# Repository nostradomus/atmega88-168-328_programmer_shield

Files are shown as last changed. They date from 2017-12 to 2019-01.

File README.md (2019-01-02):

# Atmega88/168/328 ISP programmer shield for Arduino UNO boards
  and    (minimal)

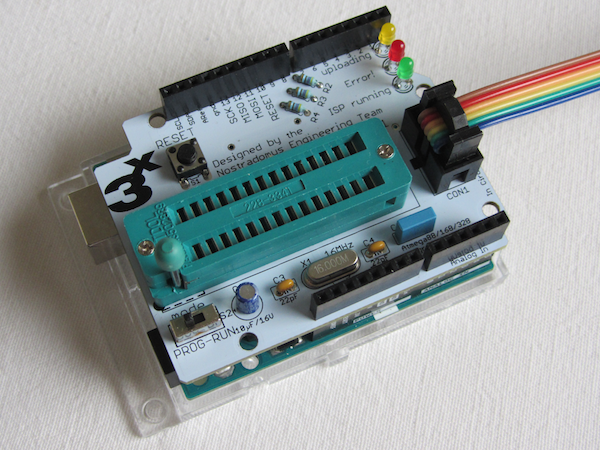
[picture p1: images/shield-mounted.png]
Shield on top of the Arduino board


## What

This repo provides you with all necessary info (and files) to build an Arduino shield to program [Atmel](http://www.atmel.com)'s **[atmega88/168/328](http://www.microchip.com/design-centers/8-bit/microchip-avr-mcus)** 𝜇-controllers. For that matter, the underlying Arduino board should be loaded with the [ISP-programmer sketch](source/ArduinoISP.ino) (built-in example). Two versions have been included. All images in the description below, refer to the 16MHz version with an external crystal oscillator. An alternative (minimalistic) version is also available in all respective sub-folders (marked as 'minimal'). It concerns a shield to program the same µ-controllers using their 8MHz internal clock.

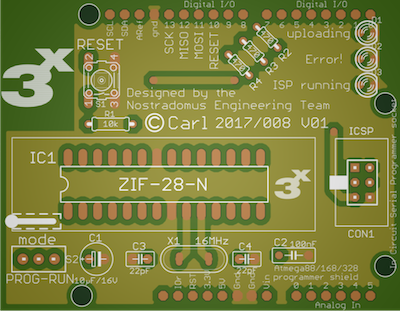
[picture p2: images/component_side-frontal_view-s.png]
PCB - component side
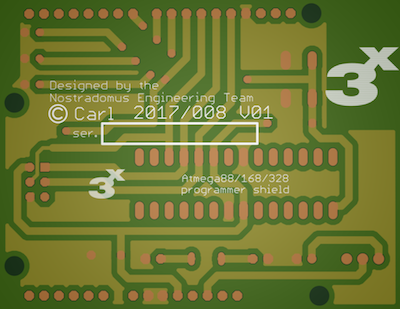
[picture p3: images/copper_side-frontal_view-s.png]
PCB - copper side
 

## Why

After having tested one of your new marvelous ideas with an existing eco-system, a lot of airwires and a piece of breadboard, you will probably start designing a state-of-the-art custom pcb to finalize the building of your project. During such a design phase, I however got tired of wiring up the ISPC connector over-and-over-again. As (like many people) I was having a spare UNO, which could serve as an [in-circuit serial programmer](https://en.wikipedia.org/wiki/In-system_programming), I decided to design a minimalistic shield to fit on top of it.  

## How

The shield has been designed with EAGLE from AutoDesk/CadSoft. This shield [project](eagle-files/) can be opened with the free version [(download here)](http://www.autodesk.com/products/eagle/free-download). Only [through-hole components](BOM.md) have been used in order to make the build also feasible for any junior electronics enthusiast. In the [pdf-folder](pdf-files/) of this repo pdf versions of all important EAGLE views are available, for those not wanting to install EAGLE. Pay attention to print the bottom and top-layer layouts **without re-sizing** (1:1). To have the printed circuit board built by a commercial PCB-shop, the full  [gerber-files](gerber-files/) are also available. When etching the board at home, don't forget to add the vias, or solder pieces of wire from solder to component side.

Currently, unpopulated boards for both the full and minimalistic version are still available from our workshop. If interested, [contact us via   :email:](http://nostradomus.ddns.net/contactform.html).

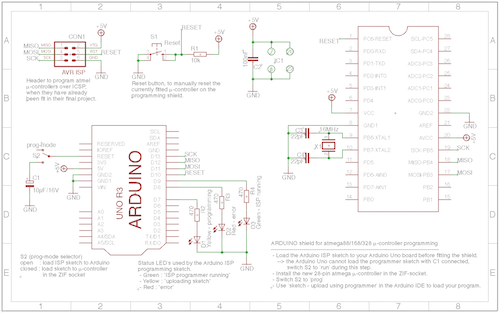
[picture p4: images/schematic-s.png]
Schematic
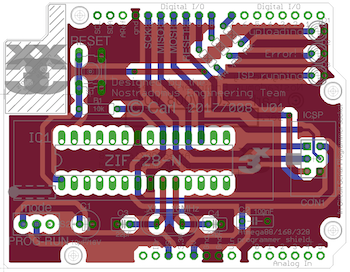
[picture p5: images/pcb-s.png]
PCB
 

## Technical details

### What’s on the board

The board has been fit with a narrow 28-pin [ZIF](https://en.wikipedia.org/wiki/Zero_insertion_force) socket, which is wired up to be universal for several types of AVR's. On the boarder of the PCB, pin headers with double functionality have been mounted. Pins on the bottom-side to fit on the Arduino board, and feed-through female headers on the top for easy access of all Arduino connections.
The push button, is connected to the reset lines of the [AVR](https://en.wikipedia.org/wiki/Atmel_AVR) in the ZIF socket (and the ICSP on the shield) with a 10kΩ pull-up resistor. When the shield is cut correctly, the reset button for the underlying Arduino UNO should still be accessible. In order to make the Arduino Uno work as an ISP programmer a 10µF capacitor needs to be connected on its reset-line.
Three LED’s are available to visualize the correct functionality of the programming procedure.
An optional AVR ISP connector has been foreseen in order to use the shield as stand-alone with a commercial programmer.

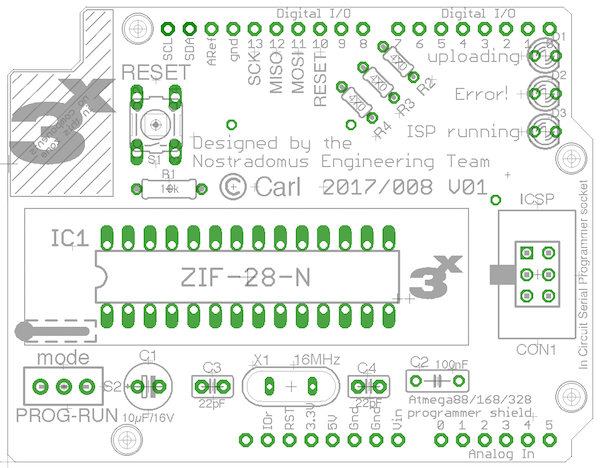
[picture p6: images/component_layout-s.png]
Component layout


#### BOM - bill of materials

Part   | Value          | Package      | Description  
------ | -------------- | ------------ | -----------                            
R1     | 10kΩ           | 0207/7       | resistor                                            
R2,3,4 | 470Ω           | 0204/5       | resistor                                            
C1     | 10µF/16V       | E2,5-6E      | polarized capacitor                                 
C2     | 100nF          | C050-025X075 | capacitor                                           
C3,4   | 22pF           | C2.5-2       | capacitor (version with xtal-oscillator)                                          
X1     | 16MHz          | QS           | oscillator crystal (version with xtal-oscillator)
LED1   | 3mm yellow     | 3mm          | LED                              
LED2   | 3mm red        | 3mm          | LED                              
LED3   | 3mm green      | 3mm          | LED
IC1    | 28-pin         | ZIF28-N      | 28-pin narrow ZIF-socket
ICSP1  | 2x3 pin-header | 2x3          | AVR ISP-6 Serial Programming Header (optional)
S1     | momentary      | 6x6x6mm      | momentary tact push button
S2     | toggle         | 9x4mm        | mini toggle switch
CON1   | 6-pin          | SIL06        | long needle female stackable pin header strip
CON2,3 | 8-pin          | SIL08        | long needle female stackable pin header strip
CON4   | 10-pin         | SIL10        | long needle female stackable pin header strip

### How things work

First the the [ISP-programmer sketch](sketches/ArduinoISP.ino) (built-in example) should be loaded to the Arduino UNO board. During that operation, switch S2 should be set to "RUN". Select “Arduino Uno” as target board in the tools-menu. Load the ISP-programmer sketch with the “UPLOAD” button. Once loaded, switch S2 can be set to "PROG" to send a sketch to the atmega 𝜇-controller in the ZIF socket.

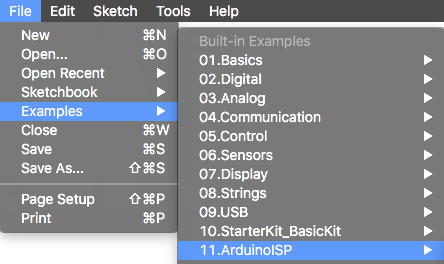
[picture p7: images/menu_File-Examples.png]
ISP example sketch
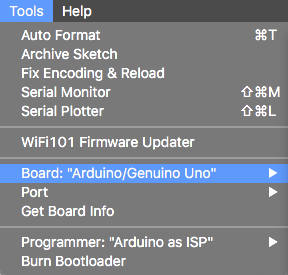
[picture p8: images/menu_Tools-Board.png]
Board selection
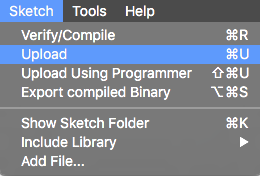
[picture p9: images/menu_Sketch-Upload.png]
Upload
  

To load a sketch to your atmega 𝜇-controller in the ZIF socket, make sure that the correct target board is selected in the tools-menu (you might need to download a specific library -> tools-menu, board manager). This time, use the “UPLOAD USING PROGRAMMER” option from the sketch-menu.

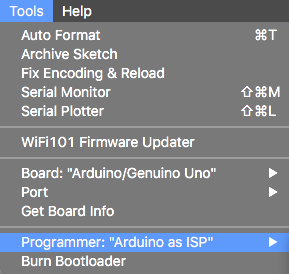
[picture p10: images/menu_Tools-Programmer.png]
Programmer selection
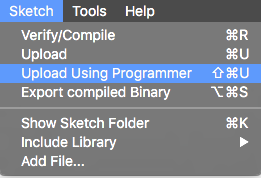
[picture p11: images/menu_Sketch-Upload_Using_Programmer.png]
Upload Using Programmer
 

When using the "8MHz internal clock" shield, an [adapted board configuration](source/minimal-boards.zip) should be used (read "fuse-settings"), which can be found in the [source-folder](source/). Other versions can be found on the [Arduino website](https://www.arduino.cc/en/Tutorial/ArduinoToBreadboard) (see paragraph on minimal hardware). To install this package driver, create a "hardware" folder in the Arduino sketches folder on your computer (path to be found in the Arduino preferences),

Preferences window

and copy the unzipped [package archive](source/minimal-boards.zip) in there.

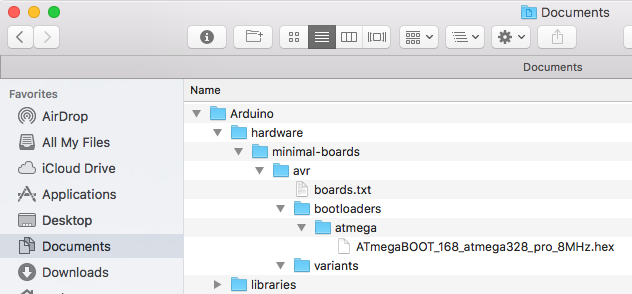
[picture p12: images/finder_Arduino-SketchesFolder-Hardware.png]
Arduino sketches folder


Next restart the Arduino IDE, and the required board will appear in your board's list.

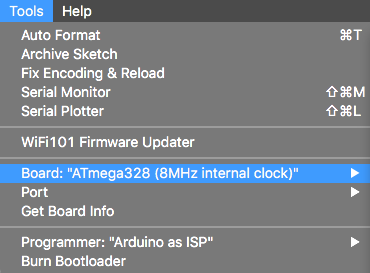
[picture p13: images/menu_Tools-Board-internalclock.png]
Board selection
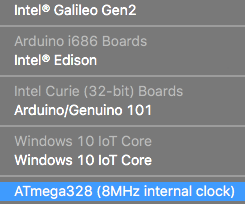
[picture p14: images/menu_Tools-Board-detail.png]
Minimal board in the board selector menu
 

When loading a new sketch to the target µ-controller, the 3 LED’s will tell you how things are going :
 - Green  : **ICSP programmer running** (fading LED means 'idle')
 - Yellow : **uploading sketch** (programming code is being uploaded)
 - Red    : **Error!** (oops, something went wrong during the upload)

### Proof of concept

So far, I have tested the shield with the below list of 𝜇-controllers :
- atmega168
- atmega328

 Programming shield should also function correctly for other pin-compatible µ-controllers, such as :
 - atmega88

## Contributors

If you are having any good suggestions, just drop me a line [:email:](http://nostradomus.ddns.net/contactform.html).
If feasible, I'll be happy to implement any proposed improvements.
And if you are having lots of time, I'll be happy to share the work with you ;-).

When you create your own version, don't forget to send us some nice pictures of your construction. We'll be happy to publish them in the :confetti_ball:Hall of Fame:confetti_ball:.

## :globe_with_meridians: License

At this moment, there is no specific license attached to this project.

So, today, if you like it, have fun with it (at your own risk of course :-D), and especially, be creative.

Oh, and when using anything from this repository, it is highly appreciated if you mention its origin.

If you would like to use any of this work (or the whole project) for commercial use, first [contact us :email:](http://nostradomus.ddns.net/contactform.html), so we can add the appropriate license, which best fits your business.

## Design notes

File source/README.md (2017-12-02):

### This folder contains Arduino sketches related to the programming shield :

 - The **ArduinoISP.ino** sketch has been added for informational purposes only. It has been copied from the Arduino.cc application, version 1.8 for MacOS. Please prioritise the use of the built-in example in the IDE on your system.

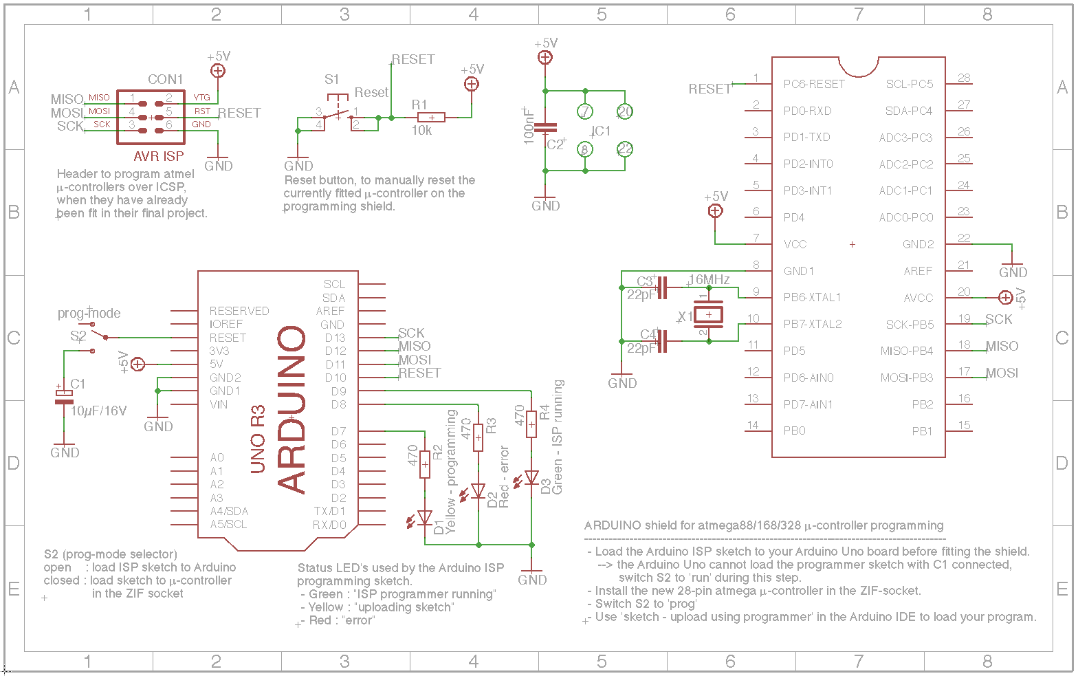
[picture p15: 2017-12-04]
images/schematic.png

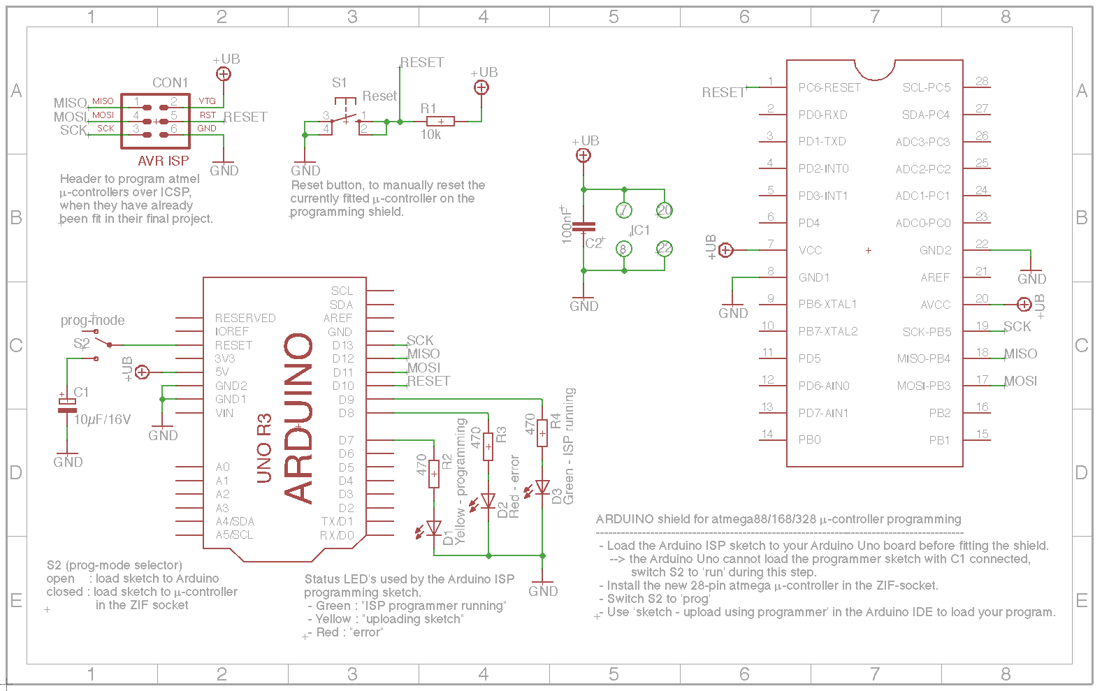
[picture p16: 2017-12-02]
images/minimal-version/schematic.png

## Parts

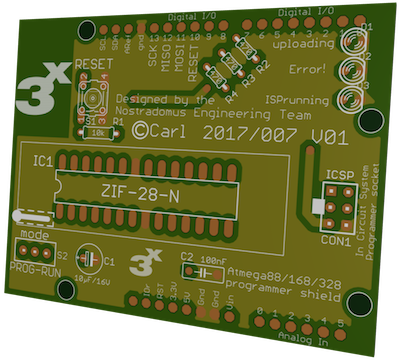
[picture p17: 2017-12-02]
images/minimal-version/component_side-right_3D_perspective-s.png

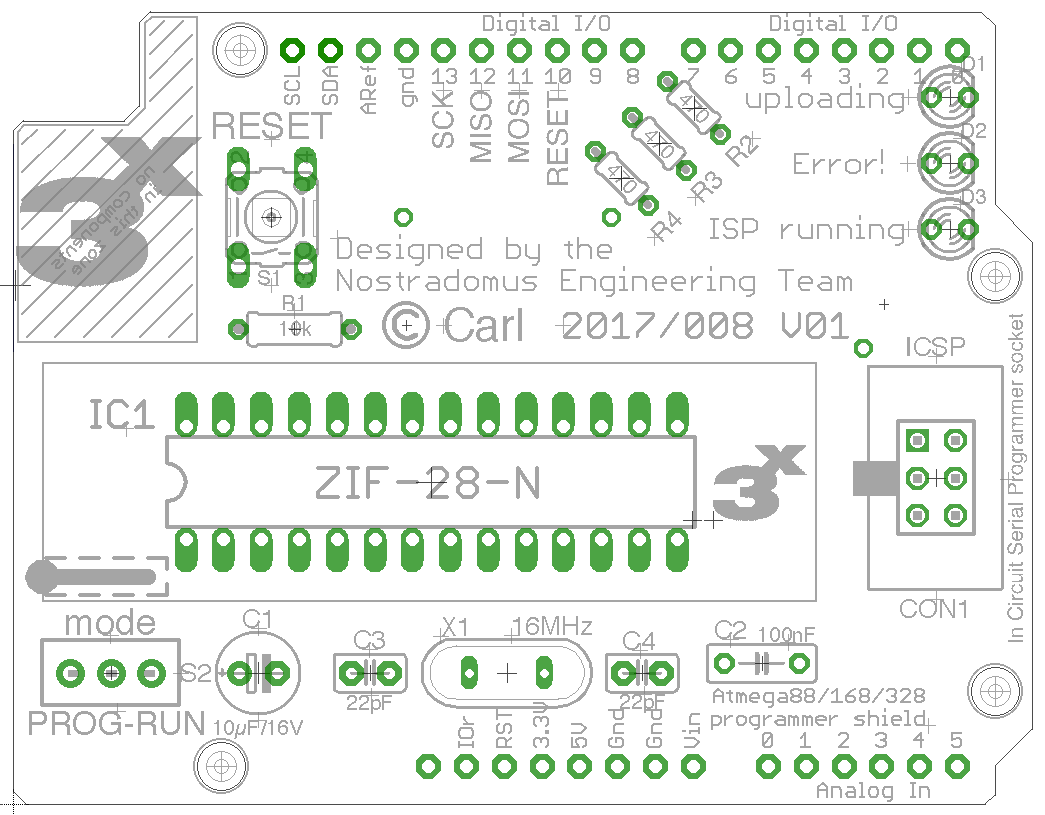
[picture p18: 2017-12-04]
images/component_layout.png

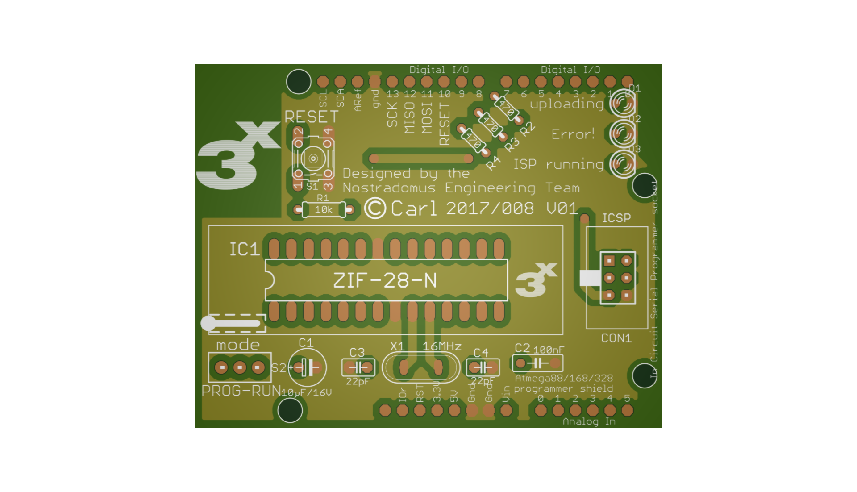
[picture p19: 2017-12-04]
images/component_side-frontal_view.png

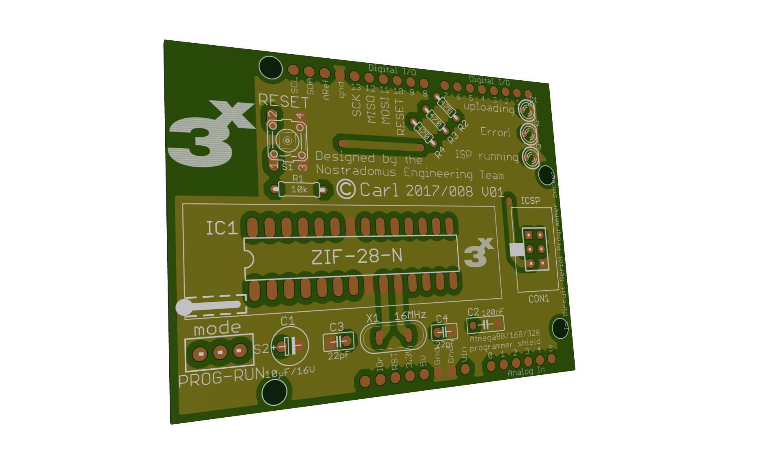
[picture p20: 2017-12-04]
images/component side - left 3D perspective.png

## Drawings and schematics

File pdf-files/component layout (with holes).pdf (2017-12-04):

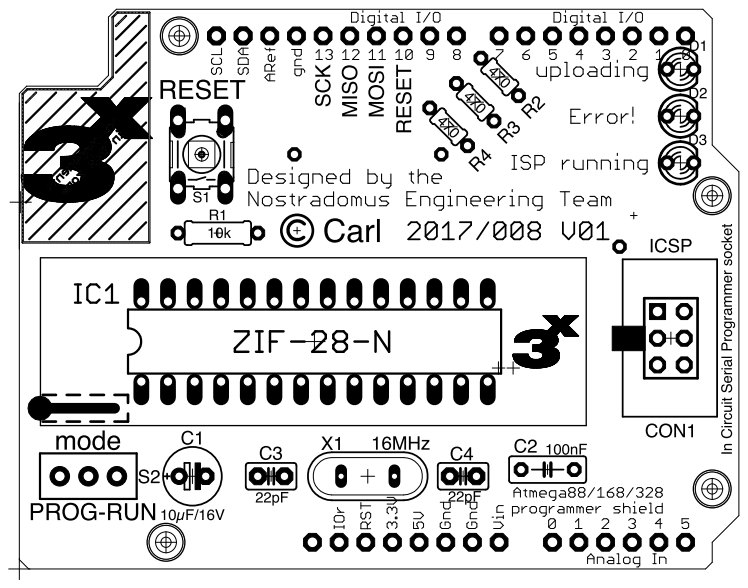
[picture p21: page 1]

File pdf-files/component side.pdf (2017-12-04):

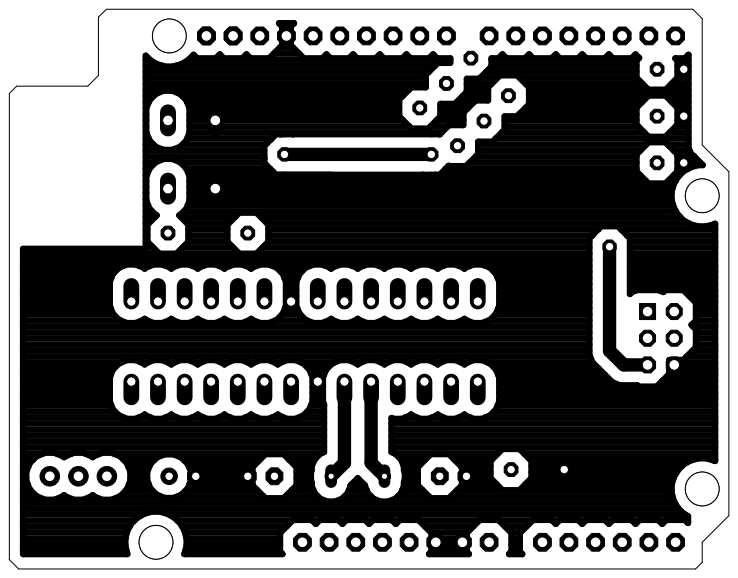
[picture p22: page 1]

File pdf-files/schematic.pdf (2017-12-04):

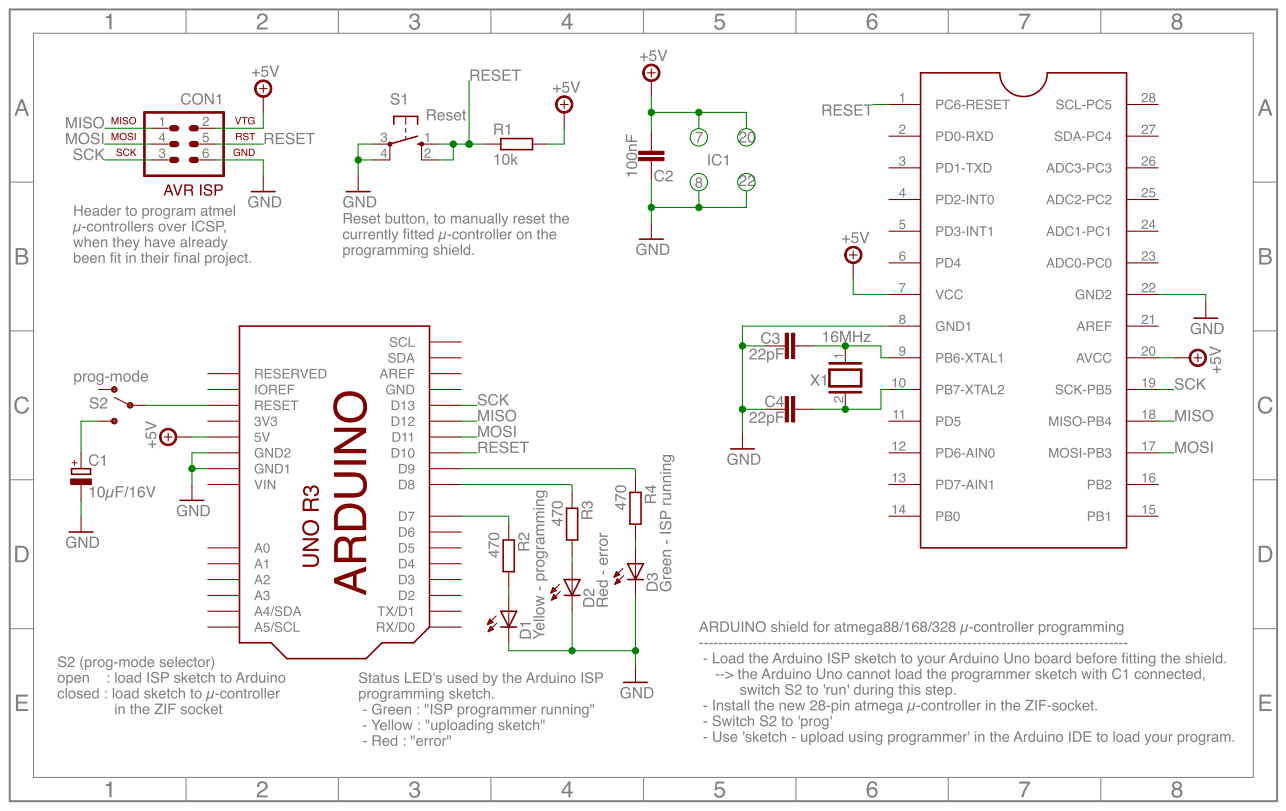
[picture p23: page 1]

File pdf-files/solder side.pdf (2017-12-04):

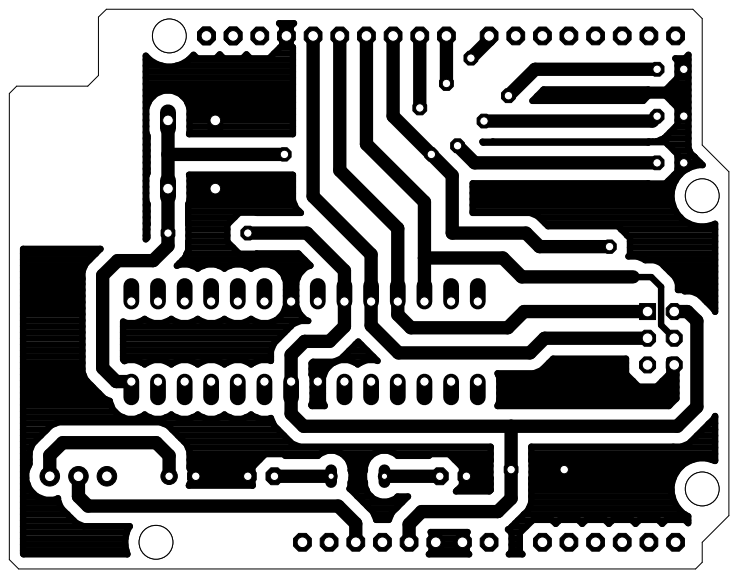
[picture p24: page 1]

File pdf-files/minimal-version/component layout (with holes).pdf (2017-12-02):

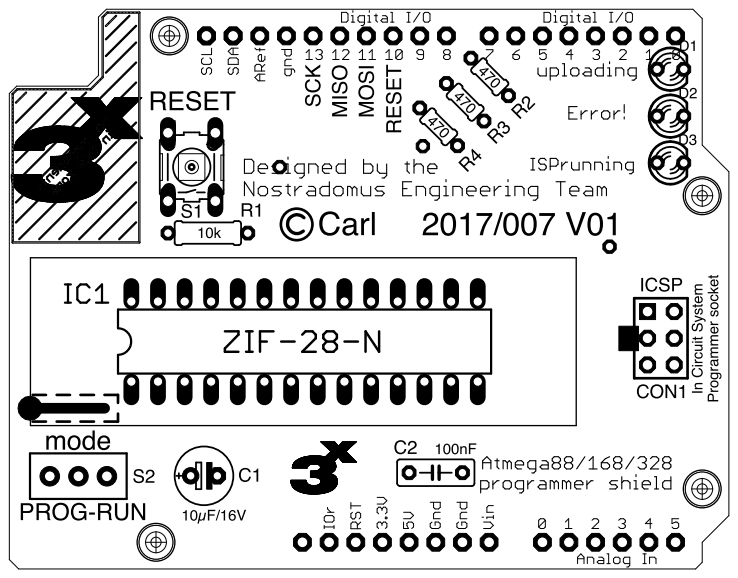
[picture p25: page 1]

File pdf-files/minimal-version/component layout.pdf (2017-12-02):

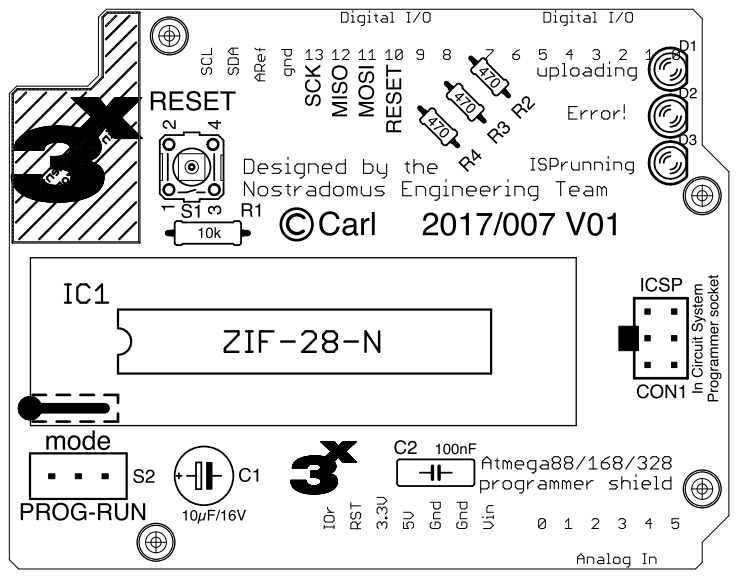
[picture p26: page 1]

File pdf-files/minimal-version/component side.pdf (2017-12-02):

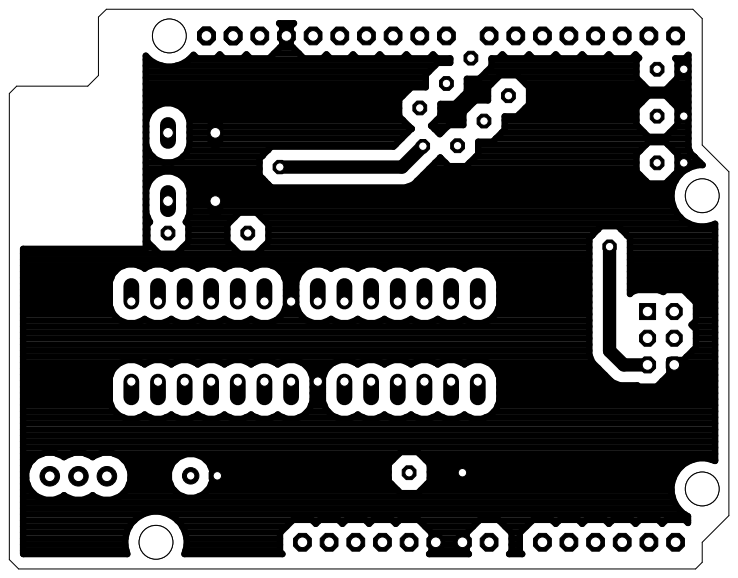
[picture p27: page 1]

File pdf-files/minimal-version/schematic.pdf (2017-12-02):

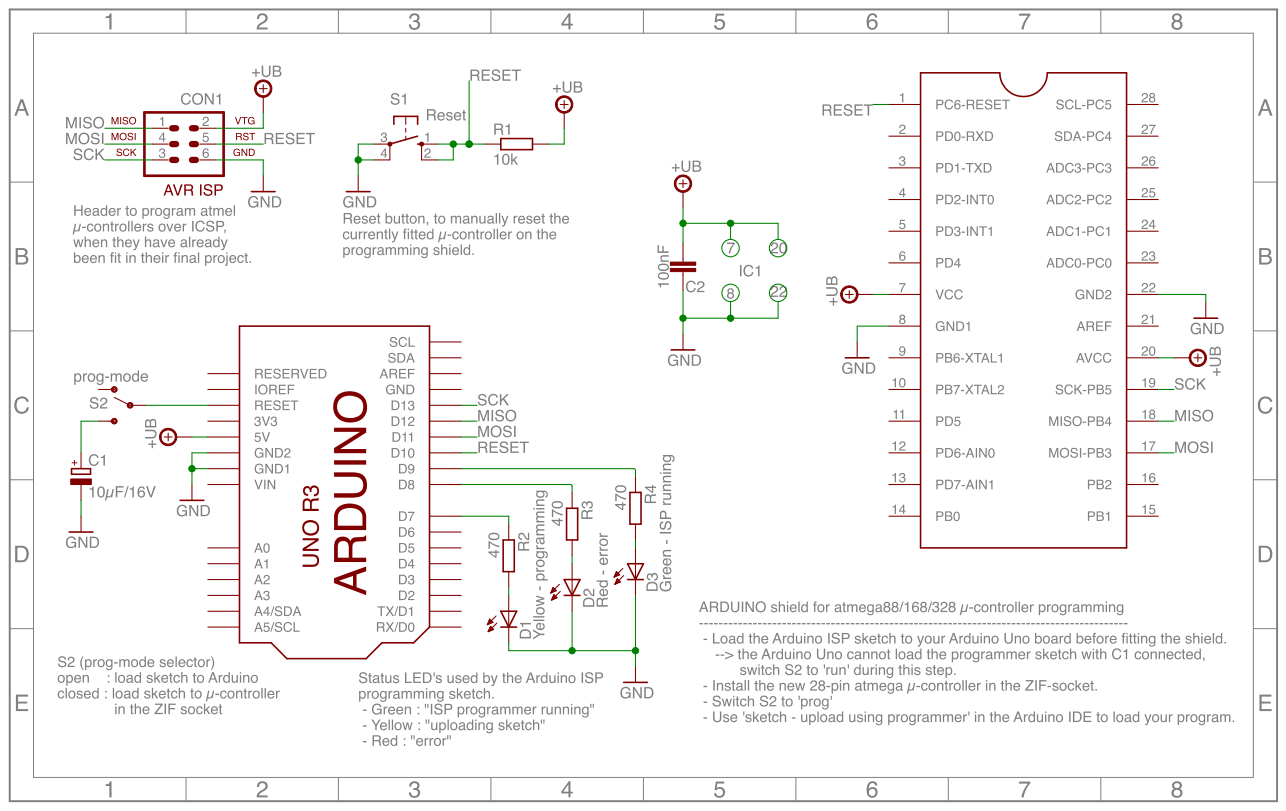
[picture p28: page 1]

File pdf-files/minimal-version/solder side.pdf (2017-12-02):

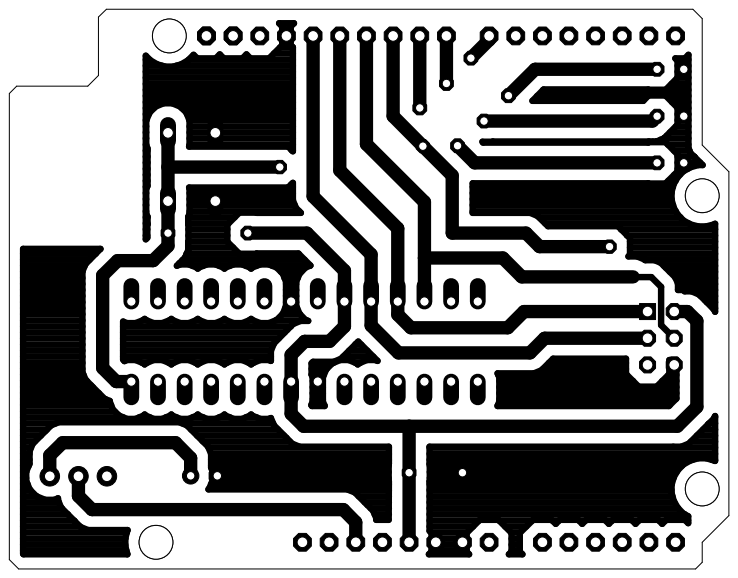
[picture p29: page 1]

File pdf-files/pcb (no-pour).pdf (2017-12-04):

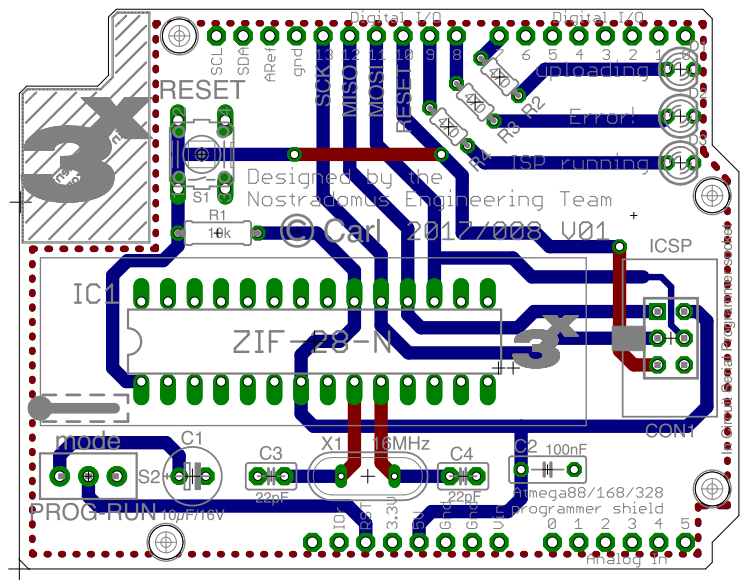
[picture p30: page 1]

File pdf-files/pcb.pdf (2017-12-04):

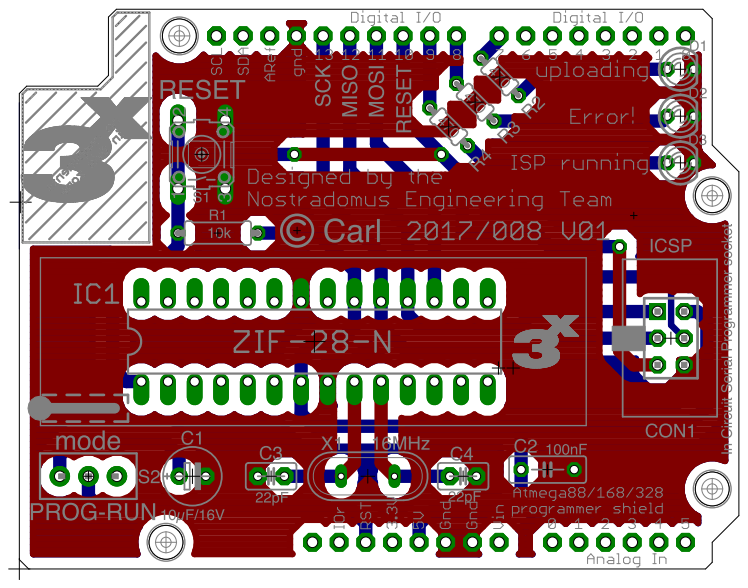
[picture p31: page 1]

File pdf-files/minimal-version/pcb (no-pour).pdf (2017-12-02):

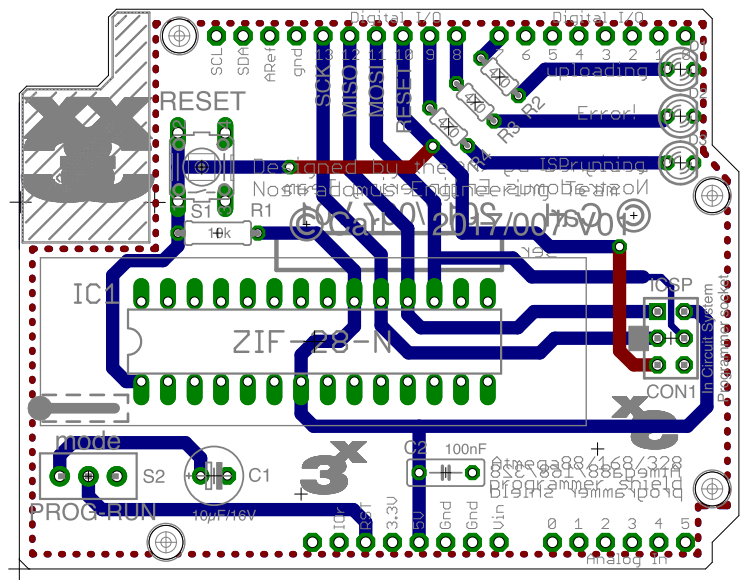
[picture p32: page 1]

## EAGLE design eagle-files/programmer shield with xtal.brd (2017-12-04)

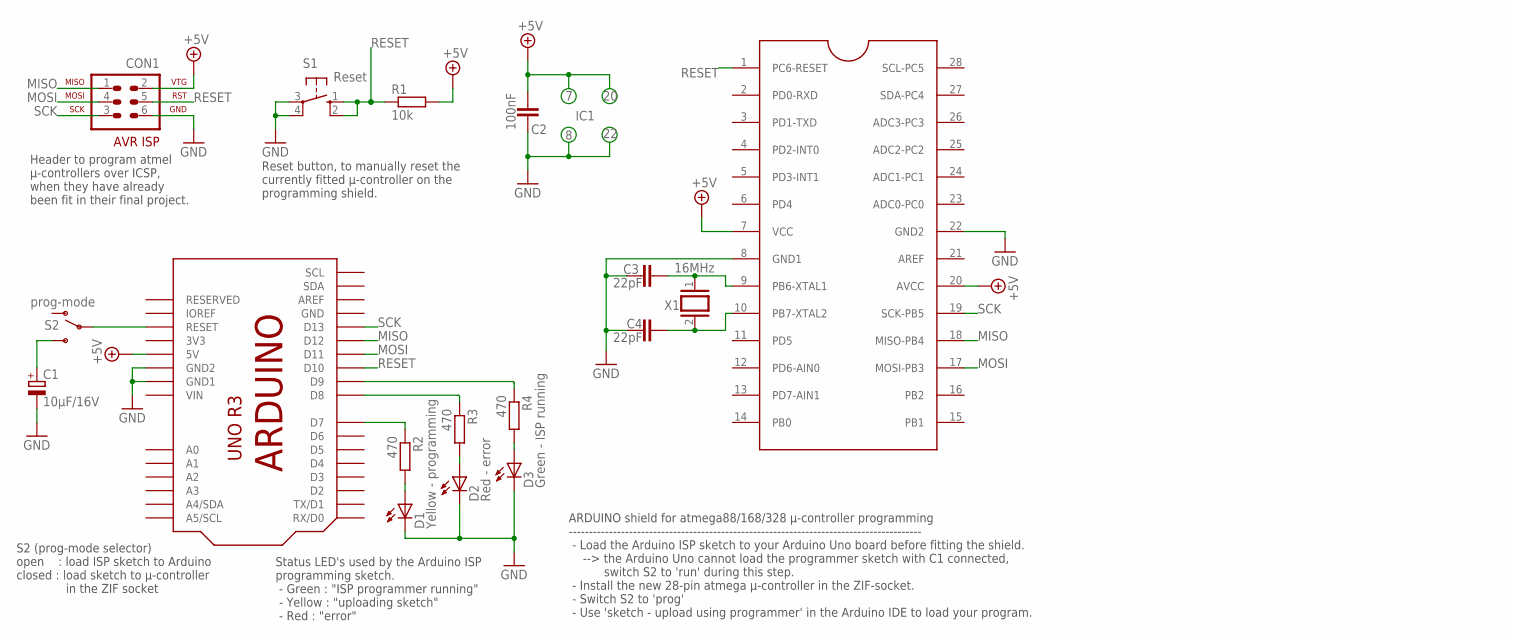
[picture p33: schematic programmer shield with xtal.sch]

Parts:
C1: 10µF/16V; E2,5-6E
C2: 100nF; C050-025X075
C3, C4: 22pF; C2.5-2
CON1: ICSP; AVR-ISP-6
D1: Yellow - programming; LED3MM
D2: Red - error; LED3MM
D3: Green - ISP running; LED3MM
IC1: Atmega88/168/328; DIL28-3-ZIF_NARROW
R1: 10k; 0207/7
R2, R3, R4: 470; 0204/5
S1: Reset; B3F-10XX
S2: prog-mode; MINI_SPDT_SWITCH-9.0X4.0MM
U$1: Arduino Uno; ARDUINO-R3
X1: 16MHz; QS

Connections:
3V3: U$1.3V (3V3)
+UB: C2.2, CON1.2, IC1.7 (VCC), IC1.20 (AVCC), R1.2, U$1.5V
GND: C1.-, C2.1, C3.1, C4.1, CON1.6, D1.K (C), D2.K (C), D3.K (C), IC1.8 (GND1), IC1.22 (GND2), S1.3, S1.4 (P1), U$1.GND, U$1.GND1, U$1.GND2
MISO: CON1.1, IC1.18 (MISO-PB4), U$1.D12
MOSI: CON1.4, IC1.17 (MOSI-PB3), U$1.D11
unnamed: C1.+, S2.3 (S)
unnamed: R4.1, U$1.D9
unnamed: R2.1, U$1.D7
unnamed: R3.1, U$1.D8
unnamed: D1.A, R2.2
unnamed: D2.A, R3.2
unnamed: D3.A, R4.2
unnamed: C3.2, IC1.9 (PB6-XTAL1), X1.1
unnamed: C4.2, IC1.10 (PB7-XTAL2), X1.2
unnamed: S2.2, U$1.RESET
RESET: CON1.5, IC1.1 (PC6-RESET), R1.1, S1.1 (S), S1.2 (S1), U$1.D10
SCK: CON1.3, IC1.19 (SCK-PB5), U$1.D13
VIN: U$1.VIN

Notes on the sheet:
IC1
Header to program atmel µ-controllers over ICSP, when they have already been fit in their final project.
Reset button, to manually reset the currently fitted µ-controller on the programming shield.
Status LED's used by the Arduino ISP programming sketch. - Green : "ISP programmer running" - Yellow : "uploading sketch" - Red : "error"
ARDUINO shield for atmega88/168/328 µ-controller programming ---------------------------------------------------------------------------------------- - Load the Arduino ISP sketch to your Arduino Uno board before fitting the shield. --> the Arduino Uno cannot load the programmer sketch with C1 conn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
S2 (prog-mode selector) open : load ISP sketch to Arduino closed : load sketch to µ-controller in the ZIF socket

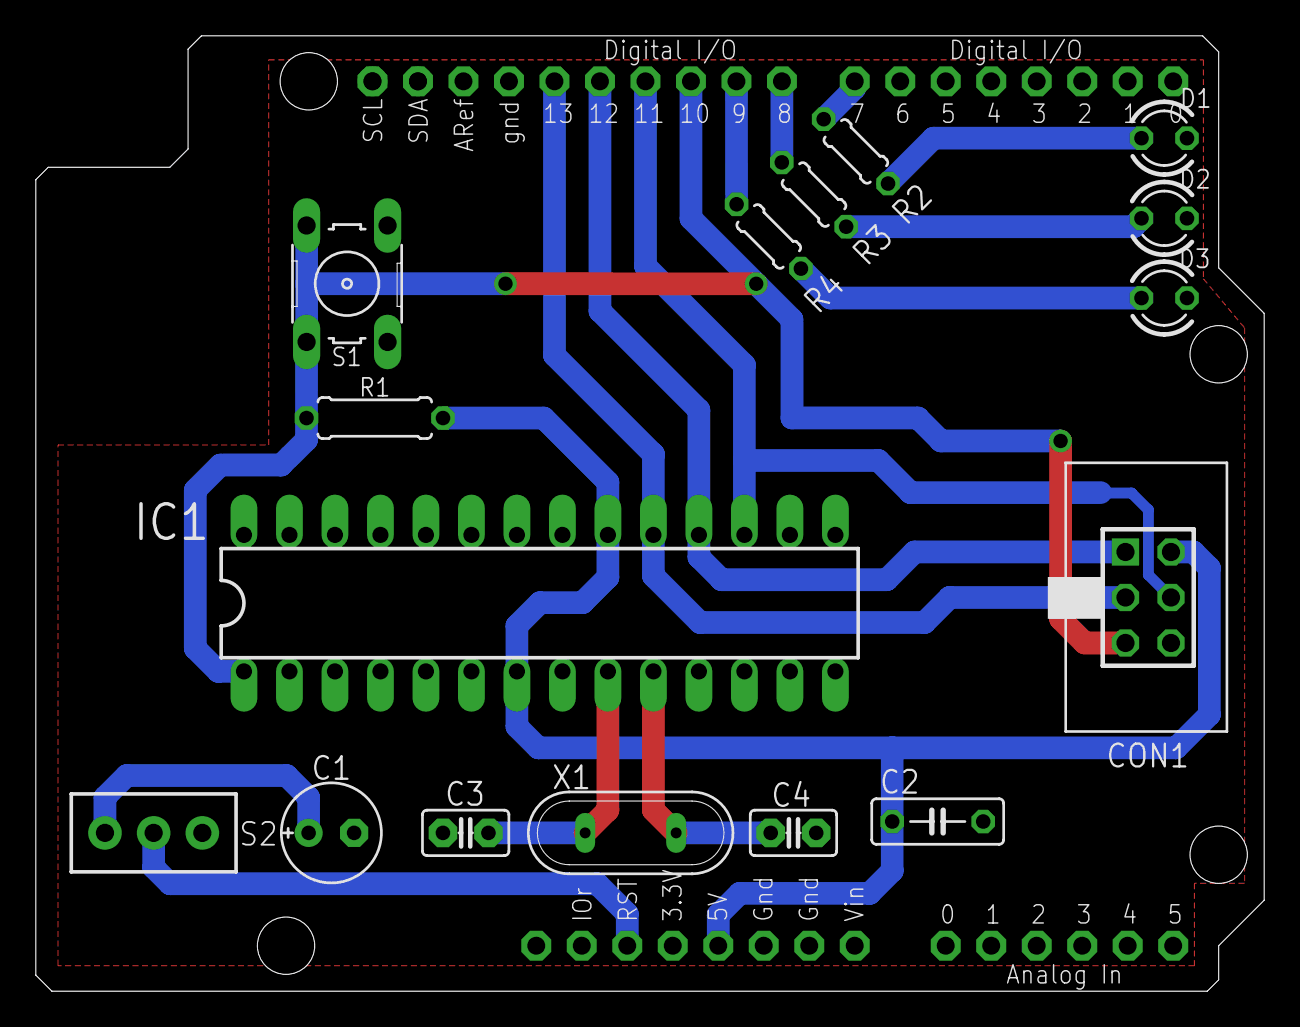
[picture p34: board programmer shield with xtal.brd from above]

Board: 2 copper layers, 68.6 x 53.3 mm, 23 parts (1 on the bottom side), 16 nets.

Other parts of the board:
U$2: COPYRIGHT-LOGO-3-B
U$3, U$7: 3X-LOGO-10-B
U$4: COPYRIGHT-LOGO-3-T
U$5: 3X-LOGO-5-B
U$6: 3X-LOGO-5-T

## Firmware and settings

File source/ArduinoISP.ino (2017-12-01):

// ArduinoISP
// Copyright (c) 2008-2011 Randall Bohn
// If you require a license, see
//     http://www.opensource.org/licenses/bsd-license.php
//
// This sketch turns the Arduino into a AVRISP
// using the following arduino pins:
//
// Pin 10 is used to reset the target microcontroller.
//
// By default, the hardware SPI pins MISO, MOSI and SCK pins are used
// to communicate with the target. On all Arduinos, these pins can be found
// on the ICSP/SPI header:
//
//               MISO °. . 5V (!) Avoid this pin on Due, Zero...
//               SCK   . . MOSI
//                     . . GND
//
// On some Arduinos (Uno,...), pins MOSI, MISO and SCK are the same pins
// as digital pin 11, 12 and 13, respectively. That is why many tutorials
// instruct you to hook up the target to these pins. If you find this wiring
// more practical, have a define USE_OLD_STYLE_WIRING. This will work even
// even when not using an Uno. (On an Uno this is not needed).
//
// Alternatively you can use any other digital pin by configuring software ('BitBanged')
// SPI and having appropriate defines for PIN_MOSI, PIN_MISO and PIN_SCK.
// 
// IMPORTANT: When using an Arduino that is not 5V tolerant (Due, Zero, ...)
// as the programmer, make sure to not expose any of the programmer's pins to 5V.
// A simple way to accomplish this is to power the complete system (programmer
// and target) at 3V3.
//
// Put an LED (with resistor) on the following pins:
// 9: Heartbeat   - shows the programmer is running
// 8: Error       - Lights up if something goes wrong (use red if that makes sense)
// 7: Programming - In communication with the slave
//

#include "Arduino.h"
#undef SERIAL


#define PROG_FLICKER true

// Configure SPI clock (in Hz).
// E.g. for an attiny @128 kHz: the datasheet states that both the high
// and low spi clock pulse must be > 2 cpu cycles, so take 3 cycles i.e.
// divide target f_cpu by 6:
//     #define SPI_CLOCK            (128000/6)
//
// A clock slow enough for an attiny85 @ 1MHz, is a reasonable default:

#define SPI_CLOCK 		(1000000/6)


// Select hardware or software SPI, depending on SPI clock.
// Currently only for AVR, for other archs (Due, Zero,...),
// hardware SPI is probably too fast anyway.

#if defined(ARDUINO_ARCH_AVR)

#if SPI_CLOCK > (F_CPU / 128)
#define USE_HARDWARE_SPI
#endif

#endif

// Configure which pins to use:

// The standard pin configuration.
#ifndef ARDUINO_HOODLOADER2 

#define RESET     10 // Use pin 10 to reset the target rather than SS
#define LED_HB    9
#define LED_ERR   8
#define LED_PMODE 7

// Uncomment following line to use the old Uno style wiring
// (using pin 11, 12 and 13 instead of the SPI header) on Leonardo, Due...

// #define USE_OLD_STYLE_WIRING

#ifdef USE_OLD_STYLE_WIRING

#define PIN_MOSI	11
#define PIN_MISO	12
#define PIN_SCK		13

#endif

// HOODLOADER2 means running sketches on the atmega16u2 
// serial converter chips on Uno or Mega boards.
// We must use pins that are broken out:
#else 

#define RESET     	4
#define LED_HB    	7
#define LED_ERR   	6
#define LED_PMODE 	5

#endif

// By default, use hardware SPI pins:
#ifndef PIN_MOSI
#define PIN_MOSI 	MOSI
#endif

#ifndef PIN_MISO
#define PIN_MISO 	MISO
#endif

#ifndef PIN_SCK
#define PIN_SCK 	SCK
#endif

// Force bitbanged SPI if not using the hardware SPI pins:
#if (PIN_MISO != MISO) ||  (PIN_MOSI != MOSI) || (PIN_SCK != SCK)
#undef USE_HARDWARE_SPI
#endif


// Configure the serial port to use.
//
// Prefer the USB virtual serial port (aka. native USB port), if the Arduino has one:
//   - it does not autoreset (except for the magic baud rate of 1200).
//   - it is more reliable because of USB handshaking.
//
// Leonardo and similar have an USB virtual serial port: 'Serial'.
// Due and Zero have an USB virtual serial port: 'SerialUSB'.
//
// On the Due and Zero, 'Serial' can be used too, provided you disable autoreset.
// To use 'Serial': #define SERIAL Serial

#ifdef SERIAL_PORT_USBVIRTUAL
#define SERIAL SERIAL_PORT_USBVIRTUAL
#else
#define SERIAL Serial
#endif


// Configure the baud rate:

#define BAUDRATE	19200
// #define BAUDRATE	115200
// #define BAUDRATE	1000000


#define HWVER 2
#define SWMAJ 1
#define SWMIN 18

// STK Definitions
#define STK_OK      0x10
#define STK_FAILED  0x11
#define STK_UNKNOWN 0x12
#define STK_INSYNC  0x14
#define STK_NOSYNC  0x15
#define CRC_EOP     0x20 //ok it is a space...

void pulse(int pin, int times);

#ifdef USE_HARDWARE_SPI
#include "SPI.h"
#else

#define SPI_MODE0 0x00

class SPISettings {
public:
  // clock is in Hz
  SPISettings(uint32_t clock, uint8_t bitOrder, uint8_t dataMode) : clock(clock){
    (void) bitOrder;
    (void) dataMode;
  };

private:
  uint32_t clock;

friend class BitBangedSPI;
};

class BitBangedSPI {
public:
  void begin() {
    digitalWrite(PIN_SCK, LOW);
    digitalWrite(PIN_MOSI, LOW);
    pinMode(PIN_SCK, OUTPUT);
    pinMode(PIN_MOSI, OUTPUT);
    pinMode(PIN_MISO, INPUT);
  }

  void beginTransaction(SPISettings settings) {
    pulseWidth = (500000 + settings.clock - 1) / settings.clock;
    if (pulseWidth == 0)
      pulseWidth = 1;
  }

  void end() {}

  uint8_t transfer (uint8_t b) {
    for (unsigned int i = 0; i < 8; ++i) {
      digitalWrite(PIN_MOSI, (b & 0x80) ? HIGH : LOW);
      digitalWrite(PIN_SCK, HIGH);
      delayMicroseconds(pulseWidth);
      b = (b << 1) | digitalRead(PIN_MISO);
      digitalWrite(PIN_SCK, LOW); // slow pulse
      delayMicroseconds(pulseWidth);
    }
    return b;
  }

private:
  unsigned long pulseWidth; // in microseconds
};

static BitBangedSPI SPI;

#endif

void setup() {
  SERIAL.begin(BAUDRATE);

  pinMode(LED_PMODE, OUTPUT);
  pulse(LED_PMODE, 2);
  pinMode(LED_ERR, OUTPUT);
  pulse(LED_ERR, 2);
  pinMode(LED_HB, OUTPUT);
  pulse(LED_HB, 2);

}

int error = 0;
int pmode = 0;
// address for reading and writing, set by 'U' command
unsigned int here;
uint8_t buff[256]; // global block storage

#define beget16(addr) (*addr * 256 + *(addr+1) )
typedef struct param {
  uint8_t devicecode;
  uint8_t revision;
  uint8_t progtype;
  uint8_t parmode;
  uint8_t polling;
  uint8_t selftimed;
  uint8_t lockbytes;
  uint8_t fusebytes;
  uint8_t flashpoll;
  uint16_t eeprompoll;
  uint16_t pagesize;
  uint16_t eepromsize;
  uint32_t flashsize;
}
parameter;

parameter param;

// this provides a heartbeat on pin 9, so you can tell the software is running.
uint8_t hbval = 128;
int8_t hbdelta = 8;
void heartbeat() {
  static unsigned long last_time = 0;
  unsigned long now = millis();
  if ((now - last_time) < 40)
    return;
  last_time = now;
  if (hbval > 192) hbdelta = -hbdelta;
  if (hbval < 32) hbdelta = -hbdelta;
  hbval += hbdelta;
  analogWrite(LED_HB, hbval);
}

static bool rst_active_high;

void reset_target(bool reset) {
  digitalWrite(RESET, ((reset && rst_active_high) || (!reset && !rst_active_high)) ? HIGH : LOW);
}

void loop(void) {
  // is pmode active?
  if (pmode) {
    digitalWrite(LED_PMODE, HIGH);
  } else {
    digitalWrite(LED_PMODE, LOW);
  }
  // is there an error?
  if (error) {
    digitalWrite(LED_ERR, HIGH);
  } else {
    digitalWrite(LED_ERR, LOW);
  }

  // light the heartbeat LED
  heartbeat();
  if (SERIAL.available()) {
    avrisp();
  }
}

uint8_t getch() {
  while (!SERIAL.available());
  return SERIAL.read();
}
void fill(int n) {
  for (int x = 0; x < n; x++) {
    buff[x] = getch();
  }
}

#define PTIME 30
void pulse(int pin, int times) {
  do {
    digitalWrite(pin, HIGH);
    delay(PTIME);
    digitalWrite(pin, LOW);
    delay(PTIME);
  } while (times--);
}

void prog_lamp(int state) {
  if (PROG_FLICKER) {
    digitalWrite(LED_PMODE, state);
  }
}

uint8_t spi_transaction(uint8_t a, uint8_t b, uint8_t c, uint8_t d) {
  SPI.transfer(a);
  SPI.transfer(b);
  SPI.transfer(c);
  return SPI.transfer(d);
}

void empty_reply() {
  if (CRC_EOP == getch()) {
    SERIAL.print((char)STK_INSYNC);
    SERIAL.print((char)STK_OK);
  } else {
    error++;
    SERIAL.print((char)STK_NOSYNC);
  }
}

void breply(uint8_t b) {
  if (CRC_EOP == getch()) {
    SERIAL.print((char)STK_INSYNC);
    SERIAL.print((char)b);
    SERIAL.print((char)STK_OK);
  } else {
    error++;
    SERIAL.print((char)STK_NOSYNC);
  }
}

void get_version(uint8_t c) {
  switch (c) {
    case 0x80:
      breply(HWVER);
      break;
    case 0x81:
      breply(SWMAJ);
      break;
    case 0x82:
      breply(SWMIN);
      break;
    case 0x93:
      breply('S'); // serial programmer
      break;
    default:
      breply(0);
  }
}

void set_parameters() {
  // call this after reading paramter packet into buff[]
  param.devicecode = buff[0];
  param.revision   = buff[1];
  param.progtype   = buff[2];
  param.parmode    = buff[3];
  param.polling    = buff[4];
  param.selftimed  = buff[5];
  param.lockbytes  = buff[6];
  param.fusebytes  = buff[7];
  param.flashpoll  = buff[8];
  // ignore buff[9] (= buff[8])
  // following are 16 bits (big endian)
  param.eeprompoll = beget16(&buff[10]);
  param.pagesize   = beget16(&buff[12]);
  param.eepromsize = beget16(&buff[14]);

  // 32 bits flashsize (big endian)
  param.flashsize = buff[16] * 0x01000000
                    + buff[17] * 0x00010000
                    + buff[18] * 0x00000100
                    + buff[19];

  // avr devices have active low reset, at89sx are active high
  rst_active_high = (param.devicecode >= 0xe0);
}

void start_pmode() {

  // Reset target before driving PIN_SCK or PIN_MOSI

  // SPI.begin() will configure SS as output,
  // so SPI master mode is selected.
  // We have defined RESET as pin 10,
  // which for many arduino's is not the SS pin.
  // So we have to configure RESET as output here,
  // (reset_target() first sets the correct level)
  reset_target(true);
  pinMode(RESET, OUTPUT);
  SPI.begin();
  SPI.beginTransaction(SPISettings(SPI_CLOCK, MSBFIRST, SPI_MODE0));

  // See avr datasheets, chapter "SERIAL_PRG Programming Algorithm":

  // Pulse RESET after PIN_SCK is low:
  digitalWrite(PIN_SCK, LOW);
  delay(20); // discharge PIN_SCK, value arbitrally chosen
  reset_target(false);
  // Pulse must be minimum 2 target CPU clock cycles
  // so 100 usec is ok for CPU speeds above 20KHz
  delayMicroseconds(100);
  reset_target(true);

  // Send the enable programming command:
  delay(50); // datasheet: must be > 20 msec
  spi_transaction(0xAC, 0x53, 0x00, 0x00);
  pmode = 1;
}

void end_pmode() {
  SPI.end();
  // We're about to take the target out of reset
  // so configure SPI pins as input
  pinMode(PIN_MOSI, INPUT);
  pinMode(PIN_SCK, INPUT);
  reset_target(false);
  pinMode(RESET, INPUT);
  pmode = 0;
}

void universal() {
  uint8_t ch;

  fill(4);
  ch = spi_transaction(buff[0], buff[1], buff[2], buff[3]);
  breply(ch);
}

void flash(uint8_t hilo, unsigned int addr, uint8_t data) {
  spi_transaction(0x40 + 8 * hilo,
                  addr >> 8 & 0xFF,
                  addr & 0xFF,
                  data);
}
void commit(unsigned int addr) {
  if (PROG_FLICKER) {
    prog_lamp(LOW);
  }
  spi_transaction(0x4C, (addr >> 8) & 0xFF, addr & 0xFF, 0);
  if (PROG_FLICKER) {
    delay(PTIME);
    prog_lamp(HIGH);
  }
}

unsigned int current_page() {
  if (param.pagesize == 32) {
    return here & 0xFFFFFFF0;
  }
  if (param.pagesize == 64) {
    return here & 0xFFFFFFE0;
  }
  if (param.pagesize == 128) {
    return here & 0xFFFFFFC0;
  }
  if (param.pagesize == 256) {
    return here & 0xFFFFFF80;
  }
  return here;
}


void write_flash(int length) {
  fill(length);
  if (CRC_EOP == getch()) {
    SERIAL.print((char) STK_INSYNC);
    SERIAL.print((char) write_flash_pages(length));
  } else {
    error++;
    SERIAL.print((char) STK_NOSYNC);
  }
}

uint8_t write_flash_pages(int length) {
  int x = 0;
  unsigned int page = current_page();
  while (x < length) {
    if (page != current_page()) {
      commit(page);
      page = current_page();
    }
    flash(LOW, here, buff[x++]);
    flash(HIGH, here, buff[x++]);
    here++;
  }

  commit(page);

  return STK_OK;
}

#define EECHUNK (32)
uint8_t write_eeprom(unsigned int length) {
  // here is a word address, get the byte address
  unsigned int start = here * 2;
  unsigned int remaining = length;
  if (length > param.eepromsize) {
    error++;
    return STK_FAILED;
  }
  while (remaining > EECHUNK) {
    write_eeprom_chunk(start, EECHUNK);
    start += EECHUNK;
    remaining -= EECHUNK;
  }
  write_eeprom_chunk(start, remaining);
  return STK_OK;
}
// write (length) bytes, (start) is a byte address
uint8_t write_eeprom_chunk(unsigned int start, unsigned int length) {
  // this writes byte-by-byte,
  // page writing may be faster (4 bytes at a time)
  fill(length);
  prog_lamp(LOW);
  for (unsigned int x = 0; x < length; x++) {
    unsigned int addr = start + x;
    spi_transaction(0xC0, (addr >> 8) & 0xFF, addr & 0xFF, buff[x]);
    delay(45);
  }
  prog_lamp(HIGH);
  return STK_OK;
}

void program_page() {
  char result = (char) STK_FAILED;
  unsigned int length = 256 * getch();
  length += getch();
  char memtype = getch();
  // flash memory @here, (length) bytes
  if (memtype == 'F') {
    write_flash(length);
    return;
  }
  if (memtype == 'E') {
    result = (char)write_eeprom(length);
    if (CRC_EOP == getch()) {
      SERIAL.print((char) STK_INSYNC);
      SERIAL.print(result);
    } else {
      error++;
      SERIAL.print((char) STK_NOSYNC);
    }
    return;
  }
  SERIAL.print((char)STK_FAILED);
  return;
}

uint8_t flash_read(uint8_t hilo, unsigned int addr) {
  return spi_transaction(0x20 + hilo * 8,
                         (addr >> 8) & 0xFF,
                         addr & 0xFF,
                         0);
}

char flash_read_page(int length) {
  for (int x = 0; x < length; x += 2) {
    uint8_t low = flash_read(LOW, here);
    SERIAL.print((char) low);
    uint8_t high = flash_read(HIGH, here);
    SERIAL.print((char) high);
    here++;
  }
  return STK_OK;
}

char eeprom_read_page(int length) {
  // here again we have a word address
  int start = here * 2;
  for (int x = 0; x < length; x++) {
    int addr = start + x;
    uint8_t ee = spi_transaction(0xA0, (addr >> 8) & 0xFF, addr & 0xFF, 0xFF);
    SERIAL.print((char) ee);
  }
  return STK_OK;
}

void read_page() {
  char result = (char)STK_FAILED;
  int length = 256 * getch();
  length += getch();
  char memtype = getch();
  if (CRC_EOP != getch()) {
    error++;
    SERIAL.print((char) STK_NOSYNC);
    return;
  }
  SERIAL.print((char) STK_INSYNC);
  if (memtype == 'F') result = flash_read_page(length);
  if (memtype == 'E') result = eeprom_read_page(length);
  SERIAL.print(result);
}

void read_signature() {
  if (CRC_EOP != getch()) {
    error++;
    SERIAL.print((char) STK_NOSYNC);
    return;
  }
  SERIAL.print((char) STK_INSYNC);
  uint8_t high = spi_transaction(0x30, 0x00, 0x00, 0x00);
  SERIAL.print((char) high);
  uint8_t middle = spi_transaction(0x30, 0x00, 0x01, 0x00);
  SERIAL.print((char) middle);
  uint8_t low = spi_transaction(0x30, 0x00, 0x02, 0x00);
  SERIAL.print((char) low);
  SERIAL.print((char) STK_OK);
}
//////////////////////////////////////////
//////////////////////////////////////////


////////////////////////////////////
////////////////////////////////////
void avrisp() {
  uint8_t ch = getch();
  switch (ch) {
    case '0': // signon
      error = 0;
      empty_reply();
      break;
    case '1':
      if (getch() == CRC_EOP) {
        SERIAL.print((char) STK_INSYNC);
        SERIAL.print("AVR ISP");
        SERIAL.print((char) STK_OK);
      }
      else {
        error++;
        SERIAL.print((char) STK_NOSYNC);
      }
      break;
    case 'A':
      get_version(getch());
      break;
    case 'B':
      fill(20);
      set_parameters();
      empty_reply();
      break;
    case 'E': // extended parameters - ignore for now
      fill(5);
      empty_reply();
      break;
    case 'P':
      if (!pmode)
        start_pmode();
      empty_reply();
      break;
    case 'U': // set address (word)
      here = getch();
      here += 256 * getch();
      empty_reply();
      break;

    case 0x60: //STK_PROG_FLASH
      getch(); // low addr
      getch(); // high addr
      empty_reply();
      break;
    case 0x61: //STK_PROG_DATA
      getch(); // data
      empty_reply();
      break;

    case 0x64: //STK_PROG_PAGE
      program_page();
      break;

    case 0x74: //STK_READ_PAGE 't'
      read_page();
      break;

    case 'V': //0x56
      universal();
      break;
    case 'Q': //0x51
      error = 0;
      end_pmode();
      empty_reply();
      break;

    case 0x75: //STK_READ_SIGN 'u'
      read_signature();
      break;

    // expecting a command, not CRC_EOP
    // this is how we can get back in sync
    case CRC_EOP:
      error++;
      SERIAL.print((char) STK_NOSYNC);
      break;

    // anything else we will return STK_UNKNOWN
    default:
      error++;
      if (CRC_EOP == getch())
        SERIAL.print((char)STK_UNKNOWN);
      else
        SERIAL.print((char)STK_NOSYNC);
  }
}
